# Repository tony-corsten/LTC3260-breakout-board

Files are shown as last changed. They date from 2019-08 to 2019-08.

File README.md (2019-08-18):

# LTC3260-breakout-board
# Overview
The LTC3260 provides a very low noise dual rail for projects requiring very stable supplies (ADCs, op amps). The main difference between the LTC3260 and the LTC3265 is the absense of a boost regulator on the LTC3260, which makes it more suitable for low voltage rails (e.g., a +/- 5V rail from a +9V battery). The negative rail is generated by an inverting charge pump directly on the input voltage. Both outputs can then be used unregulated, or using the built-in LDOs. [You can find the official documentation for the chip here](https://www.analog.com/en/products/ltc3260.html). This is a breakout board made in Kicad with a barrel jack power input [(the PJ-037A)](https://www.digikey.com/product-detail/en/cui-inc/PJ-037A/CP-037A-ND/1644545) and [SMA connectors](https://www.amazon.com/gp/product/B00G94UK74/ref=ppx_yo_dt_b_search_asin_title?ie=UTF8&psc=1) for shielded, low noise power transfer over distance. 

*_Note_*: The board is currently designed for a +/- 5V rail for a 9V battery input. You can adjust the output voltage by tweaking either voltage divider, where the specific formula for output voltage is given on page 10 of the technical manual. 

# Navigating this repo
The main folder contains relevant Kicad files (.pro, .pcb, .sch). The `gerber` directory has a PCB-fabrication ready set of gerber files. The `library` directory contains a custom kicad footprint for the PJ-037A and the SMA connector. 

# Board images
PCB Layout:
PCB Layout

Schematic:
Schematic

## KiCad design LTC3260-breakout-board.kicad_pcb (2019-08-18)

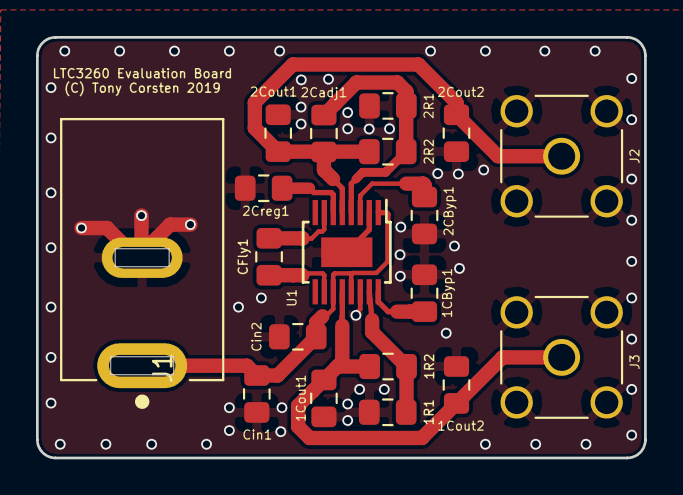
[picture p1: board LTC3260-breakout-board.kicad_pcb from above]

Board: 2 copper layers, 33.8 x 23.4 mm, 19 parts (0 on the bottom side), 11 nets.

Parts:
1CByp1, 2CByp1: 10nF; C_0805_2012Metric_Pad1.15x1.40mm_HandSolder
1Cout1, 2Cout1, 2Creg1: 10uF; C_0805_2012Metric_Pad1.15x1.40mm_HandSolder
1Cout2, 2Cout2: 0.1uF; C_0805_2012Metric_Pad1.15x1.40mm_HandSolder
1R1, 2R1: 100K; R_0805_2012Metric_Pad1.15x1.40mm_HandSolder
1R2, 2R2: 316K; R_0805_2012Metric_Pad1.15x1.40mm_HandSolder
2Cadj1: 10pF; C_0805_2012Metric_Pad1.15x1.40mm_HandSolder
CFly1: 10uF; C_0805_2012Metric_Pad1.15x1.40mm_HandSolder
Cin1: 10uF; C_0805_2012Metric_Pad1.15x1.40mm_HandSolder
Cin2: 0.1uF; C_0805_2012Metric_Pad1.15x1.40mm_HandSolder
J1: Barrel_Jack; PJ-037A
J2: -5V; SMA_Vertical_Connector
J3: +5V; SMA_Vertical_Connector
U1: LTC3260HMSE-PBF; MSOP-16-1EP_3x4mm_P0.5mm_EP1.65x2.85mm

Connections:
+9V: Cin1.1, Cin2.1, J1.1, U1.1, U1.11, U1.13
/+5V: 1Cout1.1, 1Cout2.1, 1R2.2, J3.1, U1.12
/-5V: 2Cadj1.1, 2Cout1.2, 2Cout2.2, 2R2.2, J2.1, U1.5
GND: 1CByp1.1, 1Cout1.2, 1Cout2.2, 1R1.1, 2CByp1.2, 2Cout1.1, 2Cout2.1, 2Creg1.2, 2R1.2, Cin1.2, Cin2.2, J1.2, J2.2, J3.2, U1.2, U1.14, U1.17
unnamed: 1CByp1.2, U1.16
unnamed: 1R1.2, 1R2.1, U1.15
unnamed: 2CByp1.1, U1.3
unnamed: 2Cadj1.2, 2R1.1, 2R2.1, U1.4
unnamed: 2Creg1.1, U1.6
unnamed: CFly1.1, U1.10
unnamed: CFly1.2, U1.7
